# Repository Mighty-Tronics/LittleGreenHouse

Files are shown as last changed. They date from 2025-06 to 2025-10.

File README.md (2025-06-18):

GNU General Public License v3 (GPLv3)
--------------------------------------------------------------------------------------------------------------------------
You are free to use, modify, and redistribute the code, as long as you keep the same license for your modified versions.

--------------------------------------------------------------------------------------------------------------------------

_LittleGreenHouse.ino the programm to upload in your arduino nano.

_Zip file include all librairies that must be installed in your Arduino IDE.

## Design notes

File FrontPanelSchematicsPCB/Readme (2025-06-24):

# Little Green House – Front Panel PCB (Facade)

This repository contains the KiCad files for the **Little Green House Facade PCB**, designed as the front control and interface panel for the Little Green House system. It includes interface elements such as OLED display, buttons, and status indicators, routed on a separate PCB to allow modularity and front-mounting.

## 📁 Files Overview

### 🖥️ Design Files (KiCad)
- `LittleGreenHouse-Facade.kicad_pcb`: PCB layout of the front panel
- `LittleGreenHouse-Facade.sch`: Schematic
- `LittleGreenHouse-Facade.pro`: Project settings
- `LittleGreenHouse-Facade-cache.lib`: Cached components
- `fp-info-cache`: Footprint cache (auto-generated)

### 🧾 Netlist & BOM
- `LittleGreenHouse-Facade.net`: Netlist file
- `LittleGreenHouse-Facade.xml`: XML export for online BOM tools

### 📐 Mechanical & Fabrication Files
- `LittleGreenHouse-Facade-B_Cu.dxf`, `.svg`, `.pdf`: Bottom copper layer
- `LittleGreenHouse-Facade-Edge_Cuts.dxf`, `.svg`, `.pdf`: Edge cut layer
- `LittleGreenHouse-Facade-F_SilkS.pdf`: Front silkscreen layer

### 🗃️ Backups
- `*.bak`, `*.sch-bak`: Automatic KiCad backups of schematic and PCB

## 🔧 How to Use

1. Open in **KiCad** (v6 or later).
2. Review or modify schematic and PCB.
3. Export files for CNC, milling, or manufacturing.
4. Integrate with the main **Little Green House** controller PCB.

## 📜 License

This design is published under the **CERN-OHL-S v2** license. It is freely reusable and modifiable under open hardware terms. See `LICENSE` for details.

## 🌱 About

Part of the [Little Green House Project](https://github.com/...), this front panel board is developed by **Mighty Tronics** as an open hardware interface for educational and hobbyist indoor plant automation.

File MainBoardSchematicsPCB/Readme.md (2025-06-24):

# Little Green House – Open Hardware PCB Project

This repository contains the complete KiCad project files for the **Little Green House (LG)**, an open-source smart greenhouse controller. This PCB is designed to control and automate indoor plant care with features such as real-time clock, peristaltic pump, environmental sensors, and a user interface (OLED + buttons).

## 📁 Files Overview

### 🖥️ Design Files (KiCad)
- `LittleGreenHouse.kicad_pcb`: Main PCB layout
- `LittleGreenHouse.sch`: Main schematic
- `LittleGreenHouse.pro`: Project settings
- `LittleGreenHouse-cache.lib`, `LittleGreenHouse-cache.dcm`: Cached libraries
- `LittleGreenHouse-rescue.lib`, `LittleGreenHouse-rescue.dcm`: Rescued components
- `sym-lib-table`: Symbol library table

### 🧾 BOM & Netlist
- `LittleGreenHouse.csv`: Bill of Materials (BOM)
- `LittleGreenHouse.net`: Netlist
- `LittleGreenHouse.xml`: XML export for online BOM tools

### 📐 Mechanical & Fabrication Files
- `LittleGreenHouse-B_Cu.dxf`, `.svg`, `.pdf`: Bottom copper layer
- `LittleGreenHouse-F_SilkS.pdf`: Front silkscreen layer
- `LittleGreenHouse-Edge_Cuts.dxf`, `.svg`: Edge cuts for fabrication
- `LittleGreenHouseCarbide.c2d`: Carbide Create file for CNC routing

### 📄 Documentation
- `LittleGreenHouse.pdf`: Full schematic and layout export
- `LittleGreenHouse_SVG.svg`: Combined PCB graphic

### 🗃️ Backups
- `*.bak` and `*.bck` files: Automatic KiCad backups of schematic and PCB files

## 🔧 How to Use

1. Open the project in **KiCad** (version 6 or later recommended).
2. Modify or review the schematic and PCB as needed.
3. Export Gerbers or use the included files for manufacturing.
4. Refer to the [main documentation repository](https://github.com/...) for firmware and assembly instructions.

## 📜 License

This hardware is licensed under the **CERN-OHL-S v2** (or other you prefer). You are free to use, modify, and manufacture it under open hardware principles. Please refer to the `LICENSE` file for details.

## 🌱 About

This board is part of the [Little Green House project](https://github.com/...), an open-source smart greenhouse developed by **Mighty Tronics**.

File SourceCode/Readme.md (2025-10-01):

# Little Green House – Arduino Firmware

This repository contains the Arduino source code for the **Little Green House (LG)**, an open-source indoor greenhouse controller. The firmware runs on an ATmega328P-based microcontroller (e.g., Arduino Nano) and automates plant care using sensors, actuators, and a real-time clock.

## 🌿 Features

- Automatic watering via peristaltic pump based on soil moisture
- Humidity and temperature monitoring
- Light duration tracking and LED control
- Real-time clock (RTC) for scheduled operations
- OLED screen display with current status
- Button-controlled configuration and manual triggers
- Serial interface for calibration and setup

## 🧩 Hardware Requirements

- Arduino Nano or ATmega328P-compatible board
- Soil moisture sensor
- DHT22 temperature/humidity sensor
- Light sensor (LDR or similar)
- RTC module (DS3231 recommended)
- Peristaltic pump (with driver)
- OLED 128x64 display (I2C)
- Push buttons (x3)

## 📂 File Structure

- `LittleGreenHouse.ino`: Main Arduino sketch
- `functions/*.ino`: Modularized code (triggers, setup, display, etc.)
- `lib/`: Optional custom libraries (if applicable)
- `doc/`: Additional documentation (pinout, logic, visuals)

## ⚙️ How to Upload

1. Open `LittleGreenHouse.ino` in the Arduino IDE.
2. Select **Arduino Nano** as board (or matching MCU).
3. Select the appropriate COM port.
4. Upload and monitor via serial at 9600 baud.

## 🔧 Serial Commands

The firmware supports simple serial commands for:
- Setting time and date
- Adjusting humidity/light thresholds
- Manual pump/light activation
- Debugging sensors

(See `doc/commands.md` or eBook for full list.)

## 📜 License

This firmware is released under the **MIT License**. Feel free to use, modify, and distribute it freely under open source principles.

## 🌱 About

Part of the Little Green House open hardware ecosystem by **Mighty Tronics**, this firmware brings life to the smart greenhouse controller.

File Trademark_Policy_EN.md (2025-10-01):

# Mighty Tronics® Trademark Usage Policy (v1.0)

**Mighty Tronics®** is a brand name and logo associated with electronics products, development kits, open hardware projects, and vintage audio repair services. We encourage innovation, learning, and sharing around our platform and products. To protect the community while ensuring quality and brand integrity, this policy defines how to use the *Mighty Tronics* trademark legally and respectfully.

## ✅ What you may do

- Mention *Mighty Tronics* when referring to our official products.
- Use *Mighty Tronics* to describe compatible or inspired projects (e.g., “based on a MightyDev”).
- Create tutorials, videos, articles, or training using our products (as long as they don’t appear official).
- Distribute and modify our open hardware products under their licenses, provided you don’t imply official endorsement.

## 🚫 What you may not do

- Use *Mighty Tronics*, *MightyDev*, *MightyProd*, or any related marks in your company name, product name, domain, or logo in a way that causes confusion.
- Sell a derivative or modified product using our brand without explicit permission.
- Use our logos, designs, or official visuals without authorization.
- Imply a product or content is “official” or endorsed by *Mighty Tronics* when it is not.

## 📌 Registered Trademarks

*Mighty Tronics®*, *MightyDev™*, *MightyProd™*, *Little Greenhouse™*

## 📬 Contact

[info@mightytronics.eu](mailto:info@mightytronics.eu)

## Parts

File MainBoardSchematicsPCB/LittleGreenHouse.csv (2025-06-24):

Reference | Value | Footprint | Datasheet
A1 | Arduino_Nano_Elegoo | Module:Arduino_Nano | https://content.arduino.cc/assets/NANOEveryV3.0_sch.pdf
J1 | Soil_Conn | TerminalBlock_TE-Connectivity:TerminalBlock_TE_282834-3_1x03_P2.54mm_Horizontal | ~
U2 | DHT11 | Sensor:Aosong_DHT11_5.5x12.0_P2.54mm | http://akizukidenshi.com/download/ds/aosong/DHT11.pdf
R1 | 1K | Resistor_THT:R_Axial_DIN0411_L9.9mm_D3.6mm_P25.40mm_Horizontal | ~
R3 | 10K | Resistor_THT:R_Axial_DIN0411_L9.9mm_D3.6mm_P25.40mm_Horizontal | ~
R2 | 10K | Resistor_THT:R_Axial_DIN0411_L9.9mm_D3.6mm_P25.40mm_Horizontal | ~
J2 | Oled_Conn | TerminalBlock_TE-Connectivity:TerminalBlock_TE_282834-4_1x04_P2.54mm_Horizontal | ~
SW1 | SW_Power | TerminalBlock:TerminalBlock_bornier-2_P5.08mm | ~
Q1 | BC337 | Package_TO_SOT_THT:TO-92_Horizontal2 | https://diotec.com/tl_files/diotec/files/pdf/datasheets/bc337.pdf
R8 | 330R | Resistor_THT:R_Axial_DIN0411_L9.9mm_D3.6mm_P25.40mm_Horizontal | ~
D1 | 1N4148 | Diode_THT:D_DO-35_SOD27_P7.62mm_Horizontal | https://assets.nexperia.com/documents/data-sheet/1N4148_1N4448.pdf
Q2 | 2N2222A | Package_TO_SOT_THT:TO-92_Inline | http://www.onsemi.com/pub_link/Collateral/2N2219-D.PDF
R9 | 1K | Resistor_THT:R_Axial_DIN0411_L9.9mm_D3.6mm_P25.40mm_Horizontal | ~
D2 | 1N4148 | Diode_THT:D_DO-35_SOD27_P7.62mm_Horizontal | https://assets.nexperia.com/documents/data-sheet/1N4148_1N4448.pdf
J5 | LedRamp_Conn | TerminalBlock_TE-Connectivity:TerminalBlock_TE_282834-2_1x02_P2.54mm_Horizontal | ~
K1 | SANYOU_SRD_Form_C | Relay_THT:Relay_SPDT_SANYOU_SRD_Series_Form_C | http://www.sanyourelay.ca/public/products/pdf/SRD.pdf
J6 | BP_Conn | TerminalBlock_TE-Connectivity:TerminalBlock_TE_282834-6_1x06_P2.54mm_Horizontal | ~
J4 | PUMP_Conn | TerminalBlock_TE-Connectivity:TerminalBlock_TE_282834-2_1x02_P2.54mm_Horizontal | ~
U1 | 24V to 5V | MyFootprint:Conv24DCtoDC
U3 | DS3231 | MyFootprint:DS3231_Mike
J0 | Power_Conn | TerminalBlock_TE-Connectivity:TerminalBlock_TE_282834-2_1x02_P2.54mm_Horizontal | ~

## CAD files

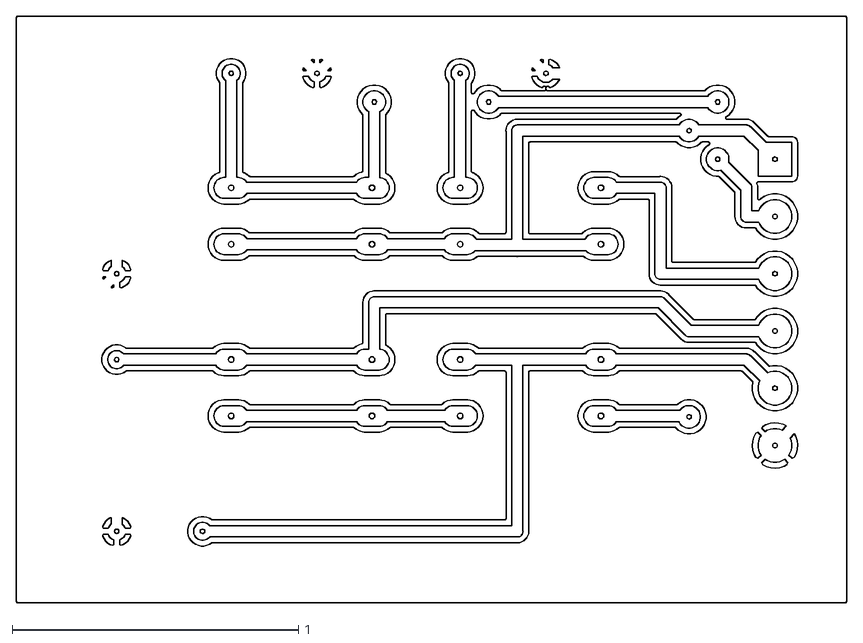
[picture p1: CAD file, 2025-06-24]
FrontPanelSchematicsPCB/LittleGreenHouse-Facade-B_Cu.dxf
2.90 x 2.05

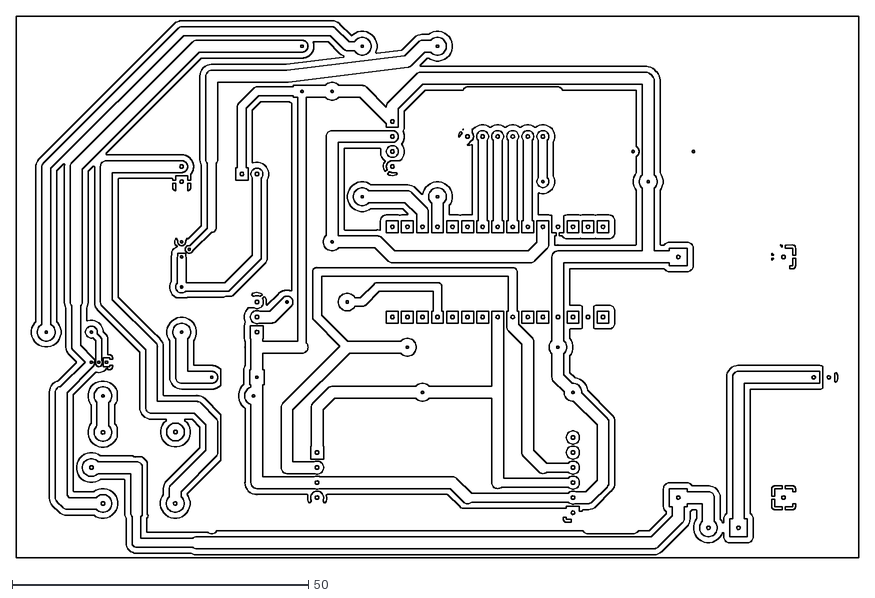
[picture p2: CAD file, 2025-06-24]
MainBoardSchematicsPCB/LittleGreenHouse-B_Cu.dxf
142.2 x 91.4

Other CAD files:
FrontPanelSchematicsPCB/LittleGreenHouse-Facade-Edge_Cuts.dxf
MainBoardSchematicsPCB/LittleGreenHouse-Edge_Cuts.dxf

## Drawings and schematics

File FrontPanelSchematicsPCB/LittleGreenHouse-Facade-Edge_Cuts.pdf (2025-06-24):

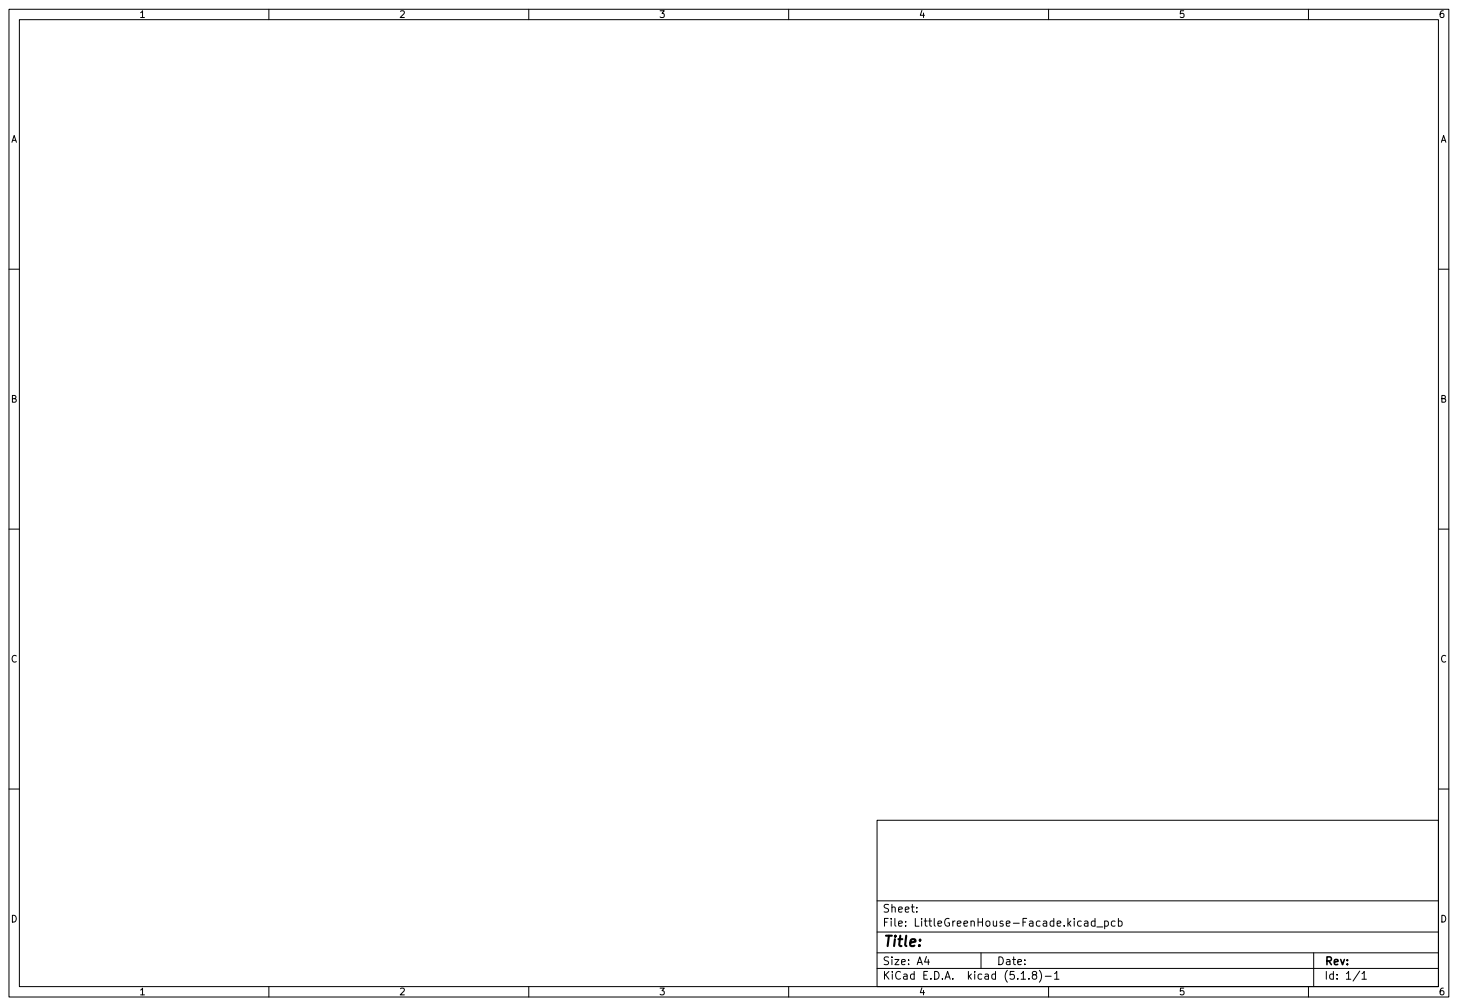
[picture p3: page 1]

File: LittleGreenHouse-Facade.kicad_pcb Sheet:
Id: 1/1 Title:

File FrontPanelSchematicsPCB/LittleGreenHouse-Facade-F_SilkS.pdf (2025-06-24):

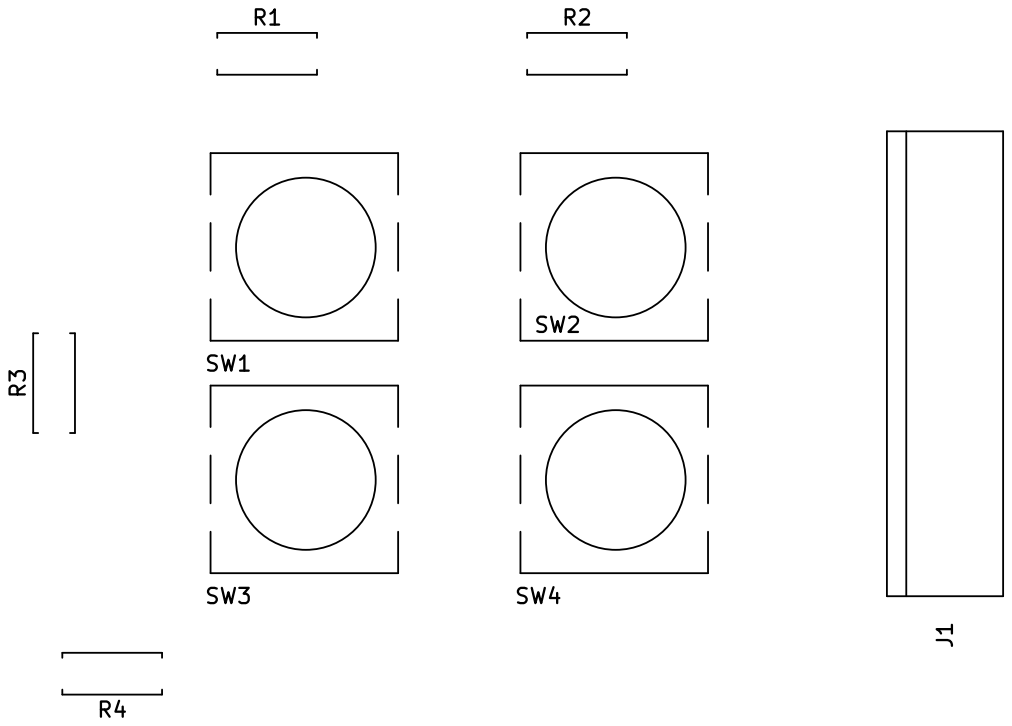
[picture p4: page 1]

File: LittleGreenHouse-Facade.kicad_pcb Sheet:
Id: 1/1 Title:

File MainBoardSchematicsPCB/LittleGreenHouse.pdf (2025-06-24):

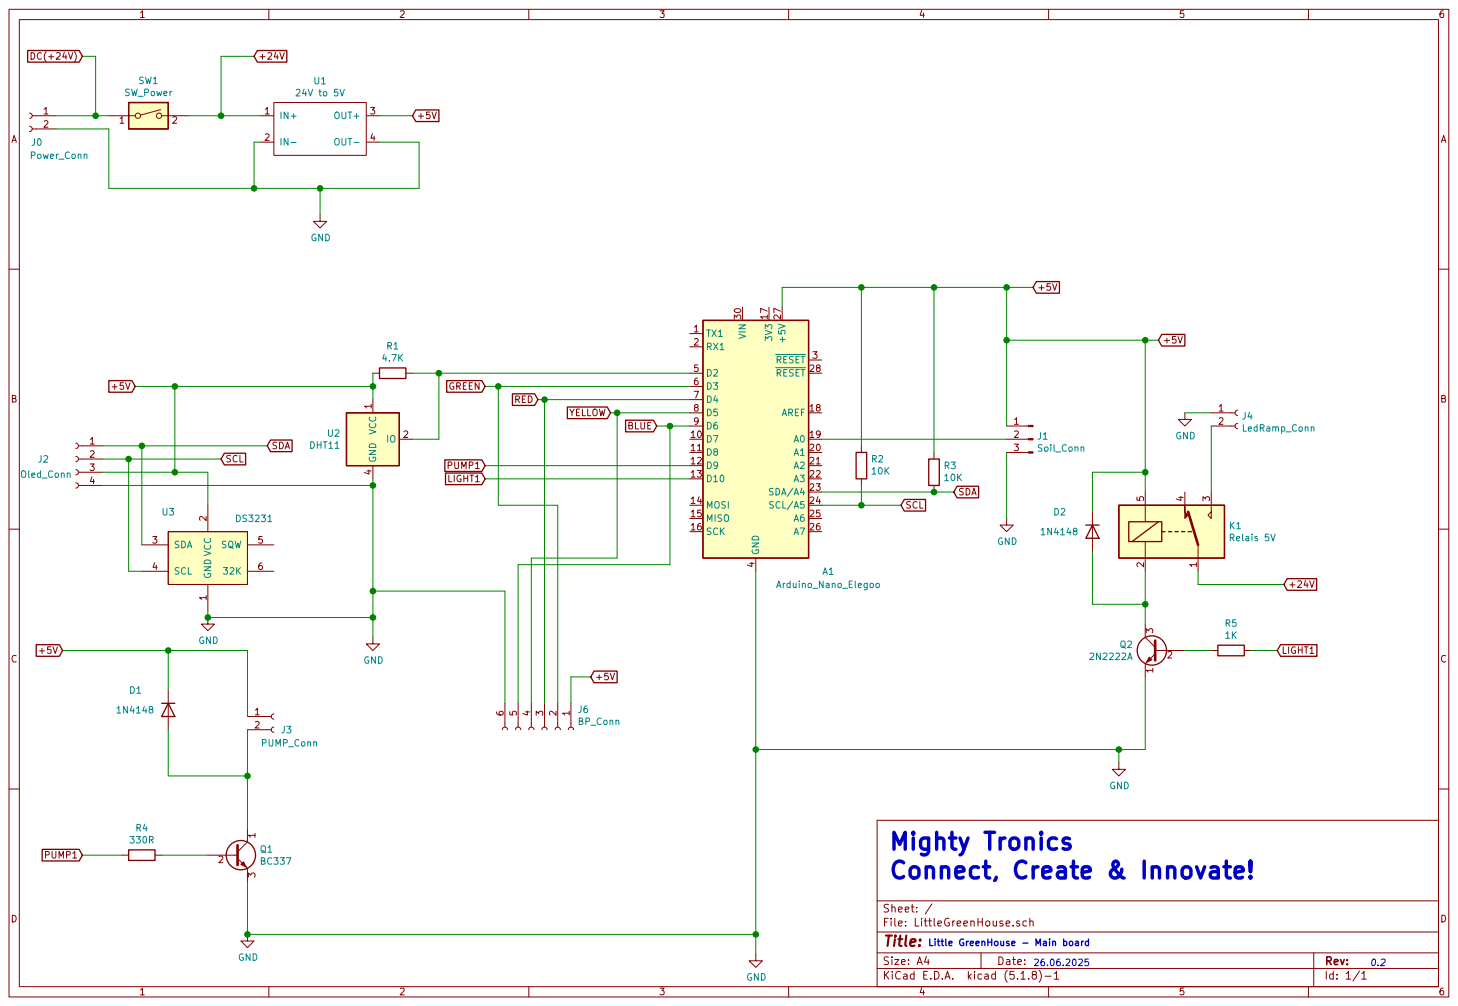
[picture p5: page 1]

Id: 1/1 Title: File: LittleGreenHouse.sch Sheet: / 1

Little GreenHouse - Main board

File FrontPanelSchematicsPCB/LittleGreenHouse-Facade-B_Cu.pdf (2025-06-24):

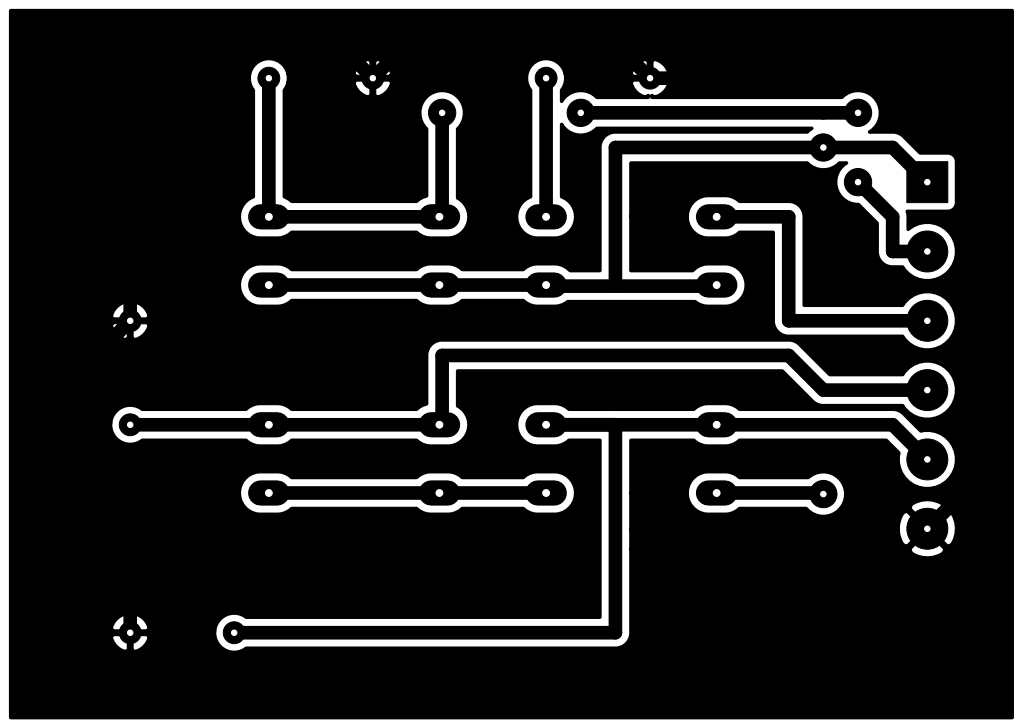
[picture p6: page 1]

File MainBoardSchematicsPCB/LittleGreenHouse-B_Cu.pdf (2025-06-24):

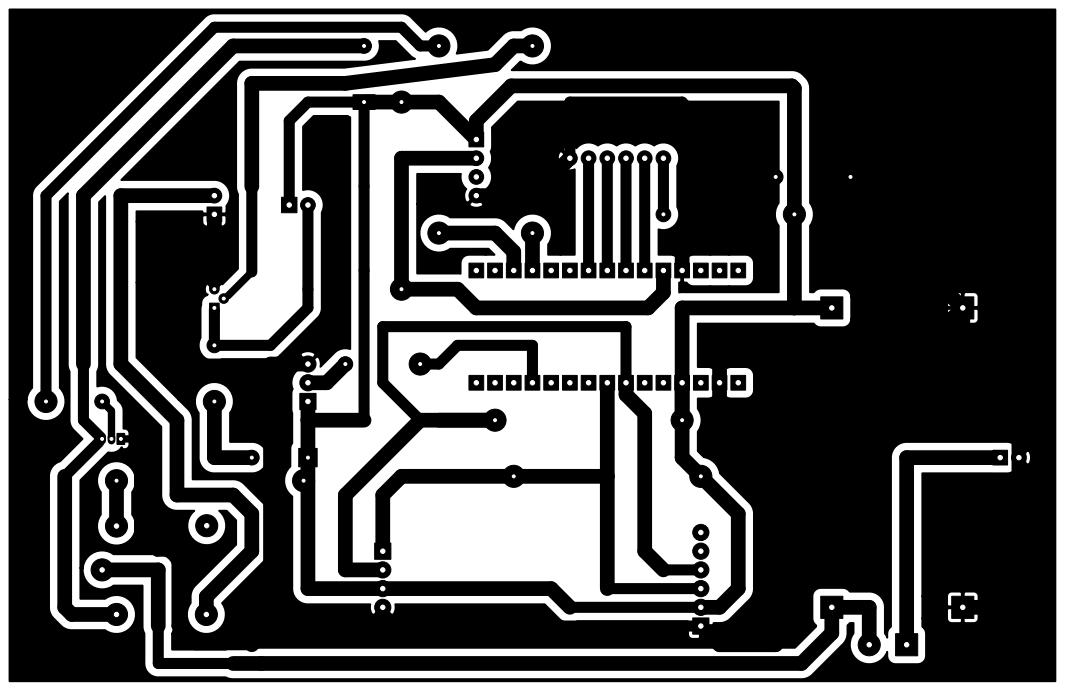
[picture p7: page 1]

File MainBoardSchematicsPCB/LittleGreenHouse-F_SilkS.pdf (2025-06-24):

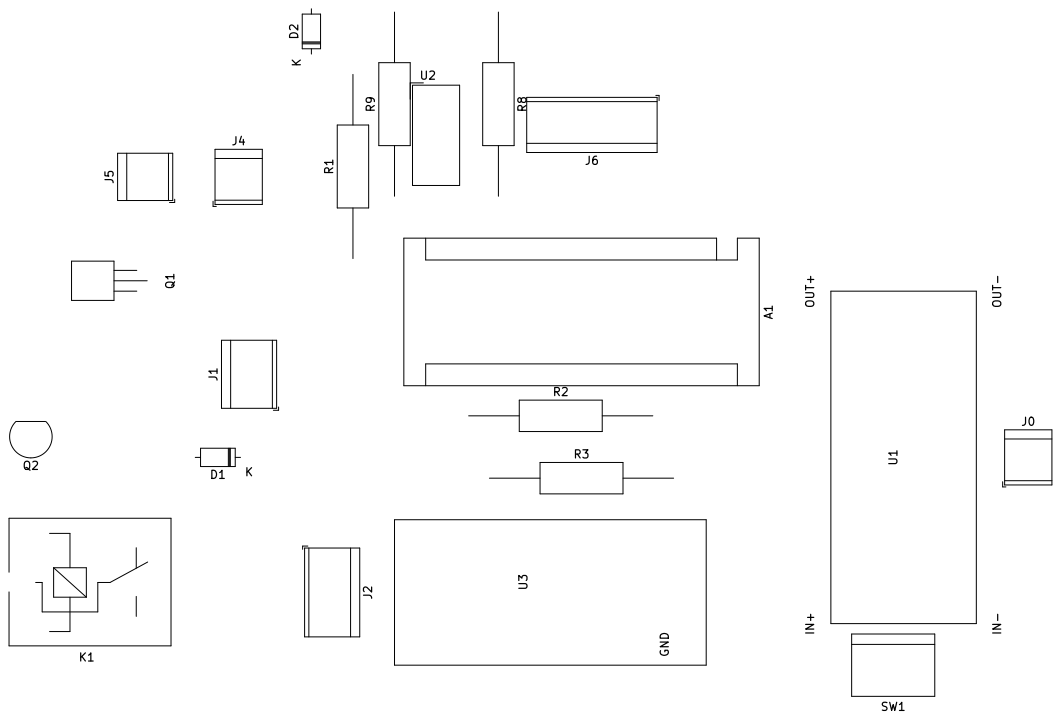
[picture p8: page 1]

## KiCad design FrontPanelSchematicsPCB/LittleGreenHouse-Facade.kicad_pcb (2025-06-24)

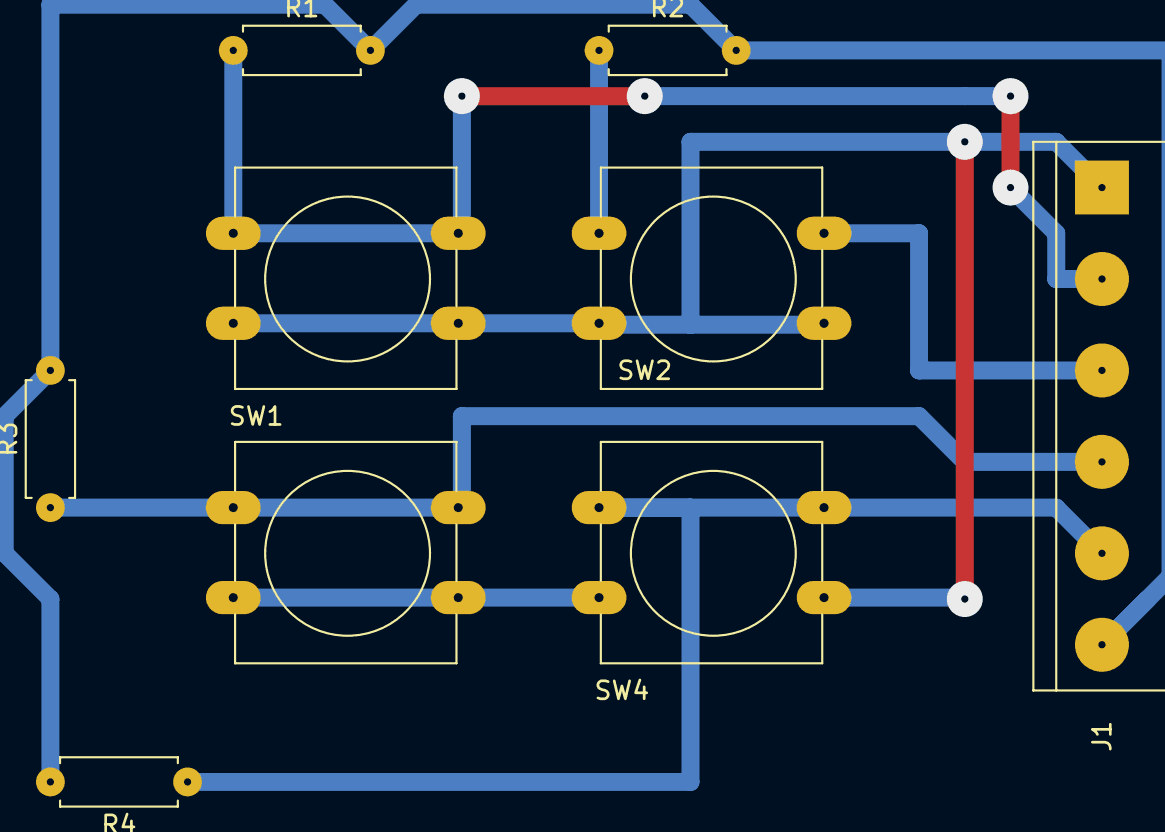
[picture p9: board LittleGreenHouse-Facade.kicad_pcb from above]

Board: 2 copper layers, 9 parts (0 on the bottom side), 6 nets.

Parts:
J1: Conn_01x06_Male; TerminalBlock_bornier-6_P5.08mm
R1, R2, R3, R4: 10K; R_Axial_DIN0207_L6.3mm_D2.5mm_P7.62mm_Horizontal
SW1: Green; SW_PUSH-12mm
SW2: RED; SW_PUSH-12mm
SW3: YELLOW; SW_PUSH-12mm
SW4: BLUE; SW_PUSH-12mm

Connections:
+5V: J1.1, SW1.2, SW2.2, SW3.2, SW4.2
BLUE: J1.5, R4.1, SW4.1
GND: J1.6, R1.2, R2.2, R3.2, R4.2
GREEN: J1.2, R1.1, SW1.1
RED: J1.3, R2.1, SW2.1
YELLOW: J1.4, R3.1, SW3.1

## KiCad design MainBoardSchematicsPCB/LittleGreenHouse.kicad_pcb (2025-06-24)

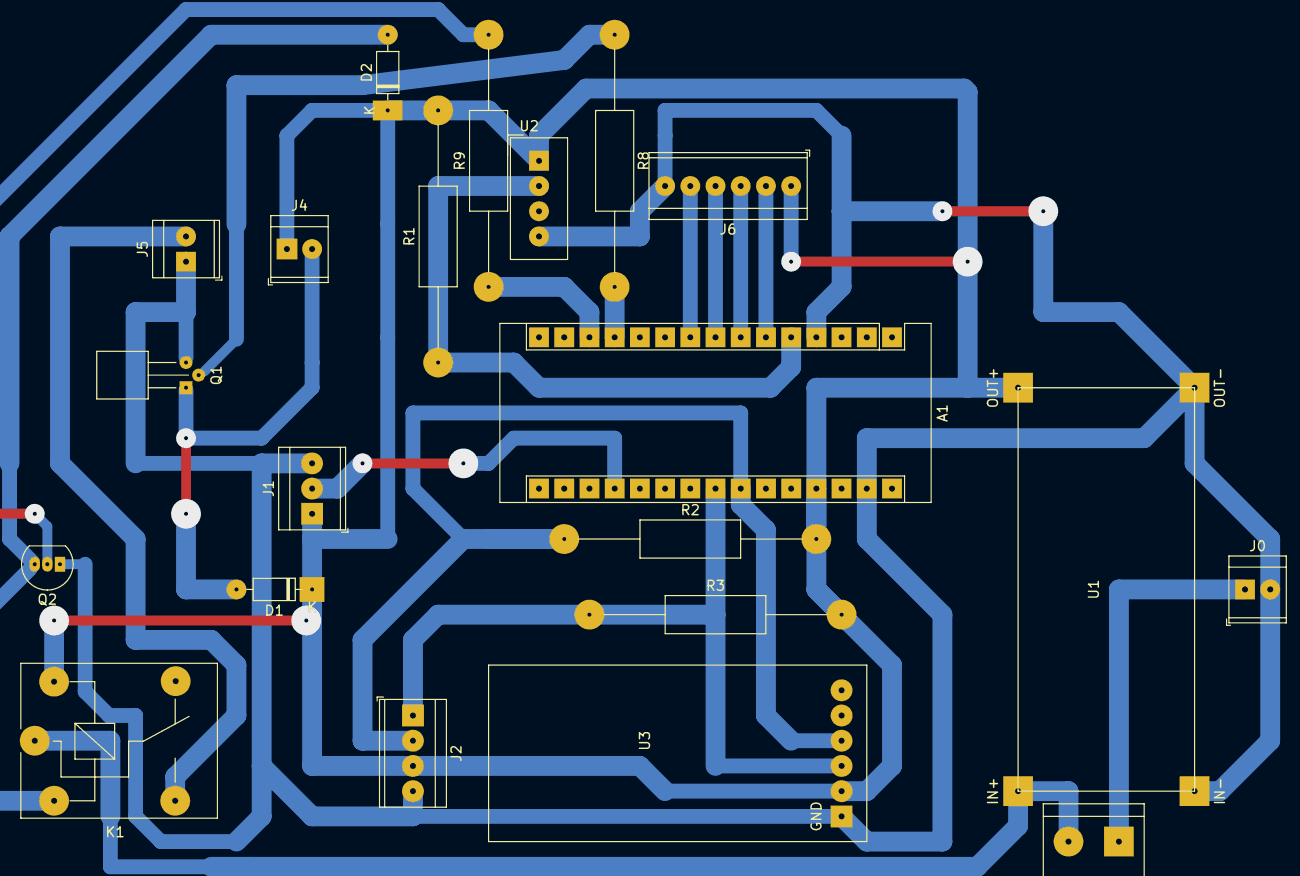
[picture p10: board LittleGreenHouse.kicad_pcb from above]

Board: 2 copper layers, 21 parts (0 on the bottom side), 19 nets.

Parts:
A1: Arduino_Nano_Elegoo; Arduino_Nano
D1, D2: 1N4148; D_DO-35_SOD27_P7.62mm_Horizontal
J0: Power_Conn; TerminalBlock_TE_282834-2_1x02_P2.54mm_Horizontal
J1: Soil_Conn; TerminalBlock_TE_282834-3_1x03_P2.54mm_Horizontal
J2: Oled_Conn; TerminalBlock_TE_282834-4_1x04_P2.54mm_Horizontal
J4: PUMP_Conn; TerminalBlock_TE_282834-2_1x02_P2.54mm_Horizontal
J5: LedRamp_Conn; TerminalBlock_TE_282834-2_1x02_P2.54mm_Horizontal
J6: BP_Conn; TerminalBlock_TE_282834-6_1x06_P2.54mm_Horizontal
K1: SANYOU_SRD_Form_C; Relay_SPDT_SANYOU_SRD_Series_Form_C
Q1: BC337; TO-92_Horizontal2
Q2: 2N2222A; TO-92_Inline
R1, R9: 1K; R_Axial_DIN0411_L9.9mm_D3.6mm_P25.40mm_Horizontal
R2, R3: 10K; R_Axial_DIN0411_L9.9mm_D3.6mm_P25.40mm_Horizontal
R8: 330R; R_Axial_DIN0411_L9.9mm_D3.6mm_P25.40mm_Horizontal
SW1: SW_Power; TerminalBlock_bornier-2_P5.08mm
U1: 24V to 5V; Conv24DCtoDC
U2: DHT11; Aosong_DHT11_5.5x12.0_P2.54mm
U3: DS3231; DS3231_Mike

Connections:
+5V: A1.27, D1.1, D2.1, J1.1, J2.3, J4.1, J6.1, K1.5, R1.2, R2.2, R3.2, U1.3, U2.1, U3.2
+24V: K1.1, SW1.2, U1.1
BLUE: A1.9, J6.5
DC(+24V): J0.1, SW1.1
GND: A1.4, A1.29, J0.2, J1.3, J2.4, J5.1, J6.6, Q1.3, Q2.1, U1.2, U1.4, U2.4, U3.1
GREEN: A1.6, J6.2
LIGHT1: A1.13, R9.1
unnamed: A1.5, R1.1, U2.2
unnamed: A1.19, J1.2
unnamed: D1.2, J4.2, Q1.1
unnamed: D2.2, K1.2, Q2.3
unnamed: J5.2, K1.3
unnamed: Q1.2, R8.1
unnamed: Q2.2, R9.2
PUMP1: A1.12, R8.2
RED: A1.7, J6.3
SCL: A1.24, J2.2, R2.1, U3.4
SDA: A1.23, J2.1, R3.1, U3.3
YELLOW: A1.8, J6.4

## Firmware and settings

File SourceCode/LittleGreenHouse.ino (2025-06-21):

//Little Greenhouse 0.1
//Code to manage a small green house for plants
//Watering based on the level of humidity of soil
//Ventilation based on the humidity and temperature of air
//Displaying on OLED environmental measures
//Capable to set triggers for watering and ventilation

//Libraries
#include "DHT.h"
#include "Wire.h"
#include <U8x8lib.h>
#include <DS3231.h>

//Setup devices

  // Setup Oled with U8x8 lib
#ifdef U8X8_HAVE_HW_SPI
#include <SPI.h>
#endif

  //Setup DHT11
#define DHTTYPE DHT11
#define DHTPIN 2

  //Set Soil sensor
#define SOILPIN A0
  
//Create devices instances
DHT dht(DHTPIN, DHTTYPE); // Humidity sensor DHT11
DS3231  rtc(SDA, SCL); // create instance for Real Time clock DS3231

//Define pins for buttons
#define GREEN 3
#define RED 4
#define YELLOW 5
#define BLUE 6
#define PUMP_WATER 9
#define LEDS 10

//Define OLED display size
//U8X8_SSD1306_128X64_NONAME_SW_I2C u8x8(/* clock=*/ SCL, /* data=*/ SDA, /* reset=*/ U8X8_PIN_NONE);   // OLEDs without Reset of the Display
U8X8_SSD1306_128X64_NONAME_HW_I2C u8x8(/* reset=*/ U8X8_PIN_NONE);   

//Intitialize triggers
int HUMSOIL = 10;
int L_DURATION = 0;
int tempH = 0 ;
int tempM = 0 ;
int startTime = 0 ;
int LstartH = 0 ;
int LstartMN = 0 ;
int LstopH = 0;
int LstopMN = 0 ;
//int minutesNow = 0 ;
//Functions

  //Display Splash Screen
 void Disp_Splash(){ 
  //Clear screen
  u8x8.clearDisplay();  
  //Display text  
  u8x8.drawString(5,1,"LITTLE");  
  u8x8.drawString(3,3,"GREENHOUSE"); 
  u8x8.drawString(5,5,"V 1.0");  
  delay(1000);
  u8x8.clearDisplay(); 
 }
 
  //Get temperature from DHT11
float Get_Temp_Air(){
  float temp_air;
  temp_air = dht.readTemperature();  
  return temp_air;
}

  //Get temperature from DHT11
float Get_Hum_Air(){
  float hum_air;
  hum_air = dht.readHumidity();
  return hum_air;
}

    //Get soil humidity from soil sensor
float Get_Hum_Soil(){
  int hum_digit;
  float hum_soil;
  float hum_step = 0.0049; 
  hum_digit = analogRead(SOILPIN);
  hum_soil = 100-(((hum_digit * hum_step)/5) * 100) ;
  return hum_soil;  
}

    //Display measures on display
void Disp_Mes(float tempA, float humA, float humS){
  u8x8.drawString(0,0,rtc.getDateStr());
  u8x8.drawString(0,1,rtc.getTimeStr());
  //Get_CurrentTime(rtc.getTimeStr());
  
  if (humS<HUMSOIL){    
    u8x8.drawString(9,1,"Dry!");
    Start_Watering(PUMP_WATER, 255, 5000);
  } 
  else  {    
    u8x8.drawString(9,1,"      ");   
  }
  u8x8.setCursor(0,3);
  u8x8.print("AIR TEMP: " + String(int(tempA)) + "C");  
  u8x8.setCursor(0,5);
  u8x8.print("AIR HUM:  " + String(int(humA)) + "%"); 
  u8x8.setCursor(0,7);
  u8x8.print("SOIL HUM: " + String(int(humS)) + "%");    
}

  //Check if setup mode is enabled to change triggers
void Check_TrigSetup(){
  if (digitalRead(GREEN)==HIGH){
    delay(3000);
    if (digitalRead(GREEN)==HIGH){
      u8x8.clearDisplay();
      u8x8.setCursor(0,0);
      u8x8.print("Enter Setup Mode");
      delay(700);
      Set_RtcTimeDate();
      Set_Hum_Trigger();
      Set_Light_Trigger();      
      //debugln("Enter Setup");
      u8x8.clearDisplay();
      u8x8.setCursor(0,0);      
      u8x8.print("Exit Setup");      
      delay(400);        
    }
  }
}

  //Set triggers to watering plants based on soil humidity level
void Set_Hum_Trigger(){        
  int tempH;
  tempH = HUMSOIL;
  
  u8x8.clearDisplay();
  do{         
    u8x8.setCursor(0,0);
    u8x8.print("SET WATER");
    u8x8.setCursor(0,2);
    u8x8.print("CURRENT: " + String(tempH) + "%");
    u8x8.setCursor(0,4);
    if (HUMSOIL<10){
      u8x8.print("NEW: 0" + String(HUMSOIL) + "%");
    }
    else{
      u8x8.print("NEW: " + String(HUMSOIL) + "%");
    }
    
    
    //Substract 5% to HUMSOIL trigger
    if (digitalRead(YELLOW)== HIGH){
      delay(500);
      if ((digitalRead(YELLOW)== LOW) && HUMSOIL>0){
        HUMSOIL = HUMSOIL -5;
        //debugln("Watering trigger: " + String(HUMSOIL));                                
      }
    }    
    //Add 5% to HUMSOIL trigger
    if (digitalRead(BLUE)== HIGH){
      delay(500);
      if ((digitalRead(BLUE)== LOW) && HUMSOIL<100){
        HUMSOIL = HUMSOIL + 5;  
        //debugln("Watering trigger: " + String(HUMSOIL));                               
      }
    }   
  }while(digitalRead(GREEN)== LOW);
  delay(1000);  
}

  //Set Lights triggers duration in hours
void Set_Light_Trigger(){        
  int tempL;
  tempL = L_DURATION;
  u8x8.clearDisplay();
   
  do{      
    u8x8.setCursor(0,0);
    u8x8.print("SET LIGHT");
    u8x8.setCursor(0,2);
    u8x8.print("CURRENT: " + String(L_DURATION) + "H");
    u8x8.setCursor(0,4);
    if (tempL<10){
      u8x8.print("NEW: 0" + String(tempL) + "H");
    }
    else{
      u8x8.print("NEW: " + String(tempL) + "H");  
    }     
    
    //Substract 1H to Light duration trigger
    if (digitalRead(YELLOW)== HIGH){
      delay(500);
      if ((digitalRead(YELLOW)== LOW) && tempL>0){
        tempL = tempL -1;
        //debugln("Light duration trigger: " + String(tempL));                                
      }
    }    
    //Add 1H to Light duration trigger
    if (digitalRead(BLUE)== HIGH){
      delay(500);
      if ((digitalRead(BLUE)== LOW) && tempL<24){
        tempL = tempL + 1;  
        //debugln("Light duration trigger: " + String(tempL));                               
      }
    }   
  }while(digitalRead(GREEN)== LOW); 
  
  if (tempL != L_DURATION){
    // set start time for the light...
    LstartH = Get_CurrentHours(rtc.getTimeStr()) ;
    LstartMN = Get_CurrentMinutes(rtc.getTimeStr()) ;
    L_DURATION = tempL;
    if (L_DURATION > 0){
      digitalWrite(LEDS,HIGH);
    }
    else if(L_DURATION == 0){
      digitalWrite(LEDS,LOW);
    }
    //Calculate stop time....
     LstopMN = LstartMN ;   
    if (LstartH + L_DURATION < 24){
      LstopH = LstartH + L_DURATION ;
    }
    else if (LstartH + L_DURATION > 24){
      LstopH = (LstartH + L_DURATION)-24 ;      
    } 
      }  
  delay(1000);
}

 //Set Hours for Real Time Clock DS3231 module
void Set_RtcTimeDate(){
  //Set Clock hours
  int tempH = Get_CurrentHours(rtc.getTimeStr()) ;
  int tempM = Get_CurrentMinutes(rtc.getTimeStr()) ;
  int tempD = Get_CurrentDay(rtc.getDateStr()) ;
  int tempMo = Get_CurrentMonth(rtc.getDateStr()) ;
  int tempY = Get_CurrentYear(rtc.getDateStr()) ;
  u8x8.clearDisplay();
  do{     
    u8x8.setCursor(0,0);
    u8x8.println("SET HOURS");    
    u8x8.setCursor(0,4);
    if (tempH<10){
      u8x8.print("Hours: 0" + String(tempH));  
    }
    else{
      u8x8.print("Hours: " + String(tempH)); 
    }    
    
    //Substract 1H to Clock
    if (digitalRead(YELLOW)== HIGH){
      delay(500);
      if ((digitalRead(YELLOW)== LOW) && tempH>0){
        tempH = tempH -1;                                    
      }
    }    
    //Add 1H toClock
    if (digitalRead(BLUE)== HIGH){
      delay(500);
      if ((digitalRead(BLUE)== LOW) && tempH<23){
        tempH = tempH + 1;                                        
      }      
    }   
  }while(digitalRead(GREEN)== LOW);  
  delay(1000);

  // Set Clock minutes
  u8x8.clearDisplay();
  do{      
    u8x8.setCursor(0,0);
    u8x8.println("SET MINUTES");    
    u8x8.setCursor(0,4);
    if (tempM<10){
      u8x8.print("Minutes: 0" + String(tempM));
    }
    else{
      u8x8.print("Minutes: " + String(tempM));
    }
    
   
    //Substract 1mn to Clock
    if (digitalRead(YELLOW)== HIGH){
      delay(500);
      if ((digitalRead(YELLOW)== LOW) && tempM>0){
        tempM = tempM -1;                                      
      }
    }    
    //Add 1mn to Clock
    if (digitalRead(BLUE)== HIGH){
      delay(500);
      if ((digitalRead(BLUE)== LOW) && tempM<59){
        tempM = tempM + 1;                           
      }
    }   
  }while(digitalRead(GREEN)== LOW);
  
  rtc.setTime(tempH, tempM, 0);
  //startTime = Get_CurrentTime(rtc.getTimeStr());
    
  delay(500);
  
  // Set Day
  u8x8.clearDisplay();
  do{      
    u8x8.setCursor(0,0);
    u8x8.println("SET DAY");    
    u8x8.setCursor(0,4);
    if (tempD<10){
      u8x8.print("Day: 0" + String(tempD));
    }
    else{
      u8x8.print("Day: " + String(tempD));
    }
    
   
    //Substract 1 to current Day
    if (digitalRead(YELLOW)== HIGH){
      delay(500);
      if ((digitalRead(YELLOW)== LOW) && tempD>1){
        tempD = tempD -1;                                      
      }
    }    
    //Add 1 to Day
    if (digitalRead(BLUE)== HIGH){
      delay(500);
      if ((digitalRead(BLUE)== LOW) && tempD<31){
        tempD = tempD + 1;                           
      }
    }   
  }while(digitalRead(GREEN)== LOW);
  
  delay(500);
  
  // Set Month
  u8x8.clearDisplay();
  do{      
    u8x8.setCursor(0,0);
    u8x8.println("SET MONTH");    
    u8x8.setCursor(0,4);
    if (tempMo<10){
      u8x8.print("Month: 0" + String(tempMo));
    }
    else{
      u8x8.print("Month: " + String(tempMo));
    }
       
    //Substract 1 to current Month
    if (digitalRead(YELLOW)== HIGH){
      delay(500);
      if ((digitalRead(YELLOW)== LOW) && tempMo>1){
        tempMo = tempMo -1;                                      
      }
    }    
    //Add 1 to current Month
    if (digitalRead(BLUE)== HIGH){
      delay(500);
      if ((digitalRead(BLUE)== LOW) && tempMo<12){
        tempMo = tempMo + 1;                           
      }
    }   
  }while(digitalRead(GREEN)== LOW);
  
  delay(500);

  // Set Year
  u8x8.clearDisplay();
  do{      
    u8x8.setCursor(0,0);
    u8x8.println("SET YEAR");    
    u8x8.setCursor(0,4);
    u8x8.print("Year: " + String(tempY));
           
    //Substract 1 to current Month
    if (digitalRead(YELLOW)== HIGH){
      delay(500);
      if ((digitalRead(YELLOW)== LOW) && tempY>2023){
        tempY = tempY -1;                                      
      }
    }    
    //Add 1 to current Month
    if (digitalRead(BLUE)== HIGH){
      delay(500);
      if ((digitalRead(BLUE)== LOW)){
        tempY = tempY + 1;                           
      }
    }   
  }while(digitalRead(GREEN)== LOW);

  rtc.setDate(tempD, tempMo, tempY);
  delay(1000);
}

  //Activate pump
void Start_Watering(int pin, int speed, int duration){
  delay(2000);
  u8x8.clearDisplay();
  u8x8.setCursor(0,4);
  u8x8.print("WATERING...");
  analogWrite(pin, speed);
  delay (duration);
  analogWrite(pin,0);  
}

  //Check if red button was pushed to amorce pump
void Check_WaterBtn(int pin, int speed){
  if (digitalRead(RED)==HIGH){
    //debugln("Manual watering started...");
    u8x8.clearDisplay();    
    do{           
        analogWrite(pin, speed);
        //debugln("Watering in progress...");
        u8x8.setCursor(3,4);
        u8x8.print("PUMP ON!");        
        delay(500);
      }while(digitalRead(RED) == HIGH);
      
    analogWrite(pin,0);
    u8x8.clearDisplay();
    u8x8.setCursor(3,4);
    u8x8.print("PUMP OFF!");     
    delay(700);
    u8x8.clearDisplay();    
    } 
  }

   //Check light duration
 void Check_LightDuration(){
   
  if (L_DURATION == 0){
    digitalWrite(LEDS, LOW);
  }
  if (L_DURATION == 24){
    digitalWrite(LEDS, HIGH);
  }

  if ((L_DURATION != 0) && (L_DURATION !=24)){
    int tempH = Get_CurrentHours(rtc.getTimeStr()) ;
    int tempM = Get_CurrentMinutes(rtc.getTimeStr()) ;
    if ((tempH == LstopH) && (tempM == LstopMN)){
      digitalWrite(LEDS, LOW);
    }   
    if ((tempH == LstartH) && (tempM == LstartMN)){
      digitalWrite(LEDS, HIGH);
    }
  }  
}

  //Get current hours
int Get_CurrentHours(String timeStr){
  String hStr;
  int hInt;
  hStr = timeStr.substring(0,2);
  hInt = hStr.toInt();
  return hInt;
}

 //Get current minutes
int Get_CurrentMinutes(String timeStr){
  String mStr;
  int mInt;
  mStr = timeStr.substring(3,5);
  mInt = mStr.toInt();
  return mInt;
}

//Get current day
int Get_CurrentDay(String dateStr){
  String dStr;
  int dInt;
  dStr = dateStr.substring(0,2);
  dInt = dStr.toInt();
  return dInt;
}

//Get current month
int Get_CurrentMonth(String dateStr){
  String mStr;
  int mInt;
  mStr = dateStr.substring(3,5);
  mInt = mStr.toInt();
  return mInt;
}

//Get current year
int Get_CurrentYear(String dateStr){
  String yStr;
  int yInt;
  yStr = dateStr.substring(6,10);
  yInt = yStr.toInt();
  return yInt;
}

//Genreral setup
void setup(){
  Serial.begin(115200);
  // Initialize DHT11 sensor
  dht.begin(); 
  
  // Initialize the rtc object 
  rtc.begin();
  //startTime = Get_CurrentTime(rtc.getTimeStr());  
  //Set input mode for buttons
  pinMode(GREEN, INPUT);
  pinMode(RED, INPUT);
  pinMode(YELLOW, INPUT);
  pinMode(BLUE, INPUT);
  //Set output mode for pump
  pinMode(PUMP_WATER, OUTPUT);
  digitalWrite(PUMP_WATER, LOW);
  //Set output mode for ramp leds
  pinMode(LEDS, OUTPUT);
  digitalWrite(LEDS, LOW);
  
  //Initialize Oled display
  u8x8.begin();
  u8x8.setPowerSave(0); 
  u8x8.setFont(u8x8_font_chroma48medium8_r); 
    
  //Call splash screen;
  Disp_Splash(); 
}

//main code
void loop() {
  float T_air, H_air, H_soil;
  T_air = Get_Temp_Air();
  H_air = Get_Hum_Air();
  H_soil = Get_Hum_Soil(); 
  Disp_Mes(T_air,H_air,H_soil); 
  Check_TrigSetup(); 
  Check_WaterBtn(PUMP_WATER,255);  
  Check_LightDuration();
}
 
